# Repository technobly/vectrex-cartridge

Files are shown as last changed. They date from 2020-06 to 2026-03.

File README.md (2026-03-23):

Vectrex Cartridge and Vectrex LED board
===

So you wanna produce a Vectrex game and you need a 32KB cartridge with high score save support? Here's your reference design! Order it as is or customize it with your own graphics.  Supports 32KB and 64KB bankswitched games.  Supports 32KB games with DS2431+ high score save.  See Schematic for configuration options.

The RGB LED is also optional, but looks great in the translucent cartridge shells.  It lights up one of 8 colors based on the Red-Green-Blue DIP switch, yes black is a color of light ;-)

What makes this Vectrex Cartridge design different from others out there?  Well, the design is originally based on Frank Buss' Vectrex cart edge connector, but it has been significantly fixed.  The soldermask has been removed from around all of the fingers, the fingers themselves are not as wide as Frank's, and the spacing of everything has been updated to match original carts as close as possible.

Yes these fit in [Sean Kelly reproduction cartridge shells](http://www.vectrexmulti.com/order2.html#!/Vectrex-Empty-Cartridge-Shells/c/38886086/offset=0&sort=normal) perfectly!

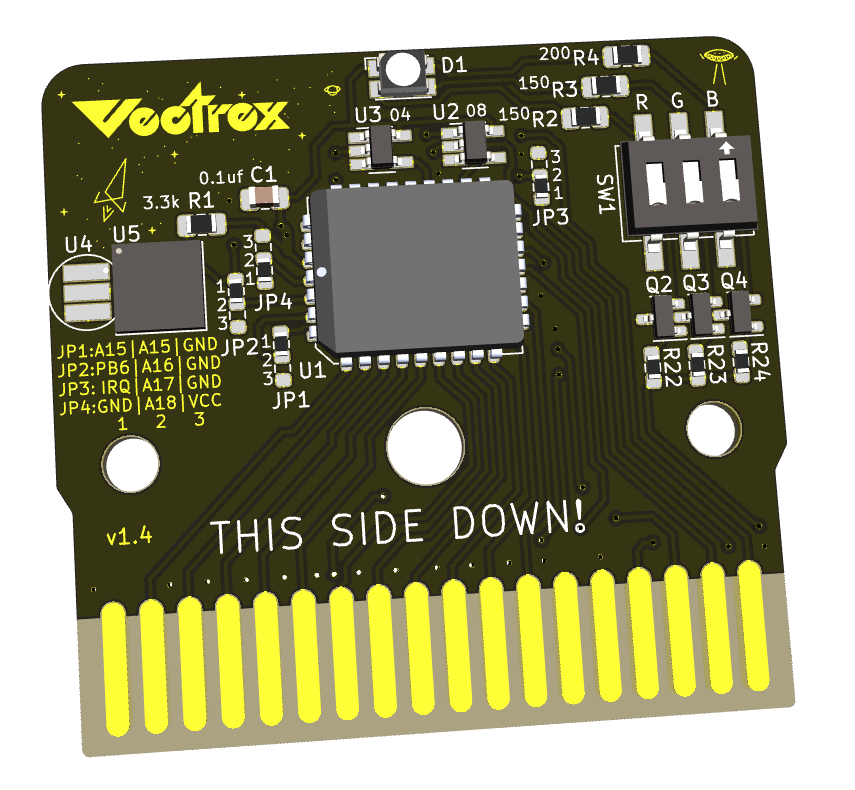
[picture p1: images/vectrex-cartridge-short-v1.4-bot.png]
v1.4 Cartridge Short Render


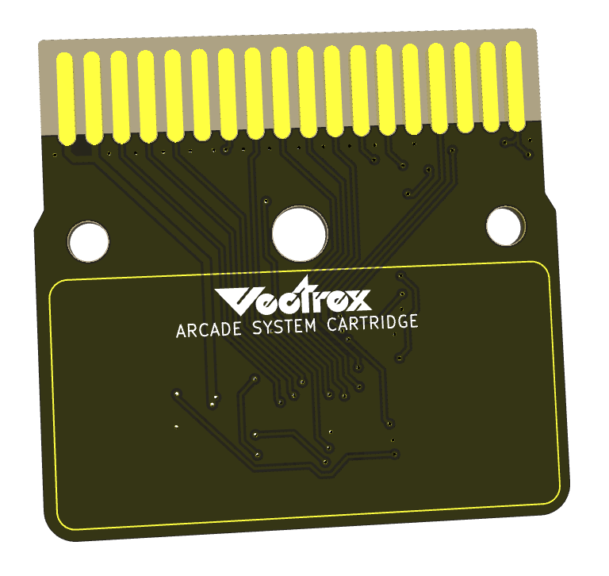
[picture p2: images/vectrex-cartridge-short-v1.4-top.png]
v1.4 Cartridge Short Render


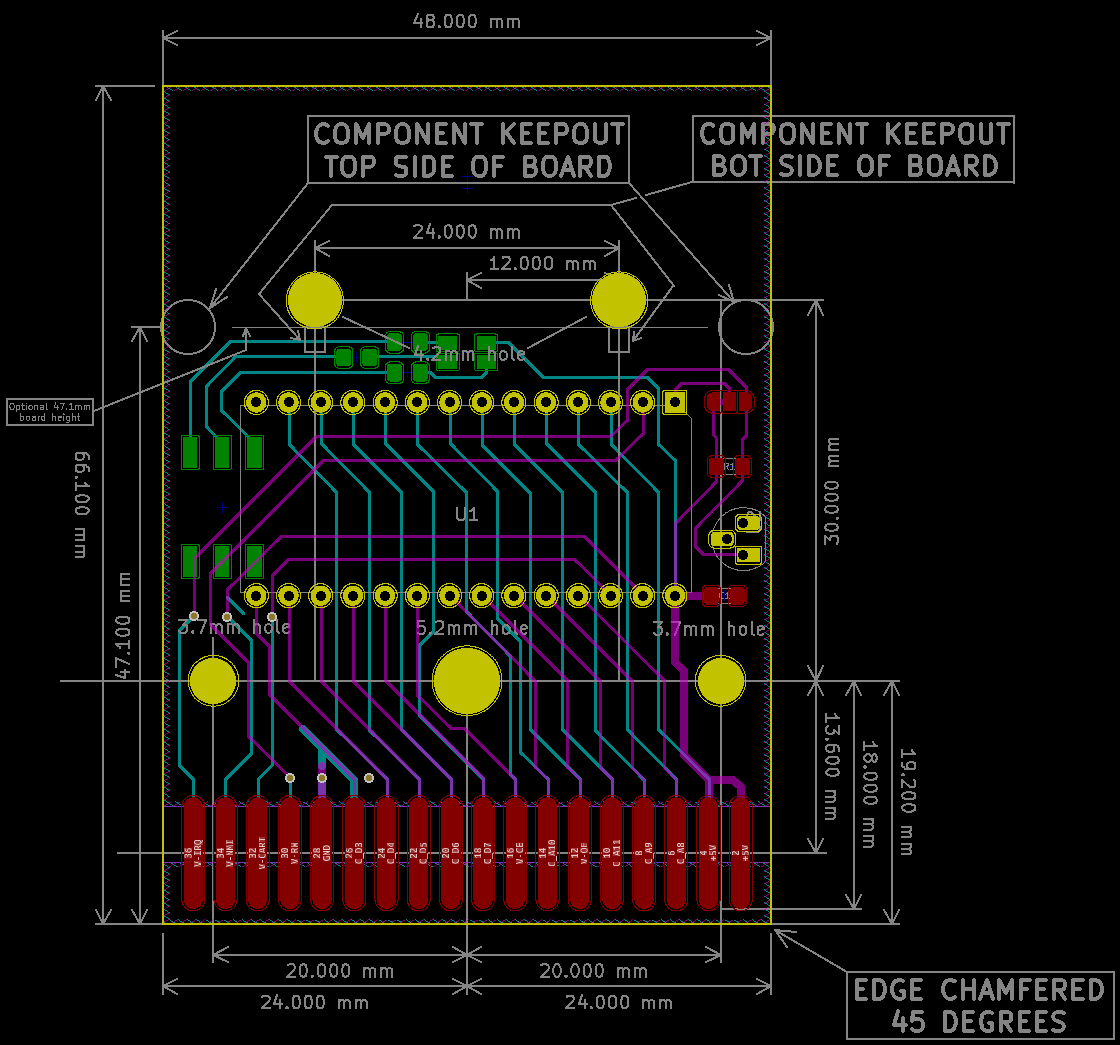
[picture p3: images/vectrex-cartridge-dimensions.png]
Dimensions


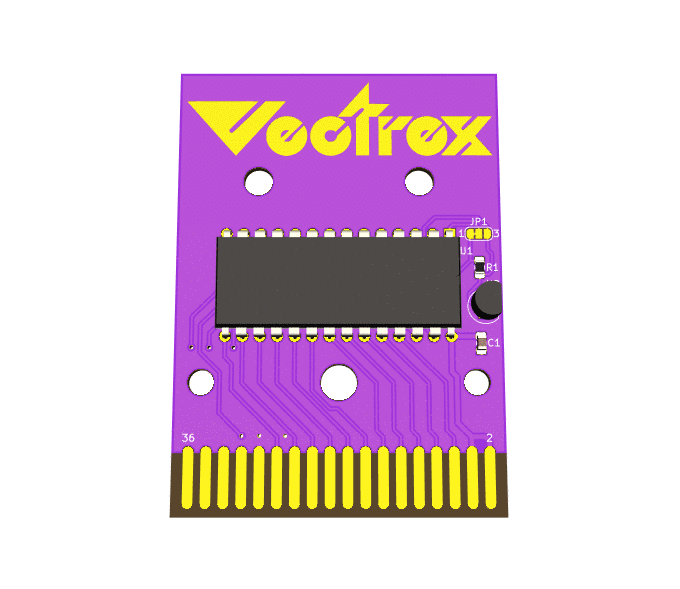
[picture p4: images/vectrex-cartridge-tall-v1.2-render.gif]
v1.2 Cartridge Render


Also included here is a simple RGB LED board add-on.  Maybe you already have a PCB but you don't have the cool LED? Easy, just add this one to the bottom.  It fits perfectly under most 28 pin 32KB/64KB EPROMS.

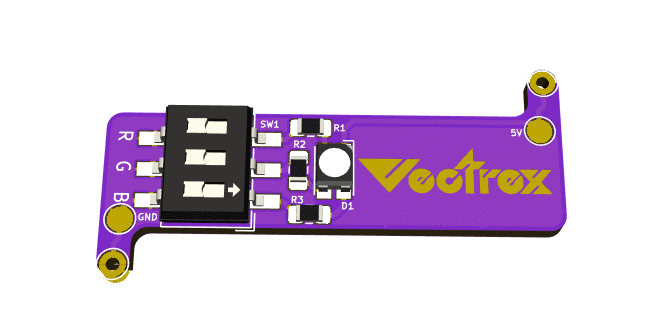
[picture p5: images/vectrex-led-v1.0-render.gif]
v1.0 LED Render


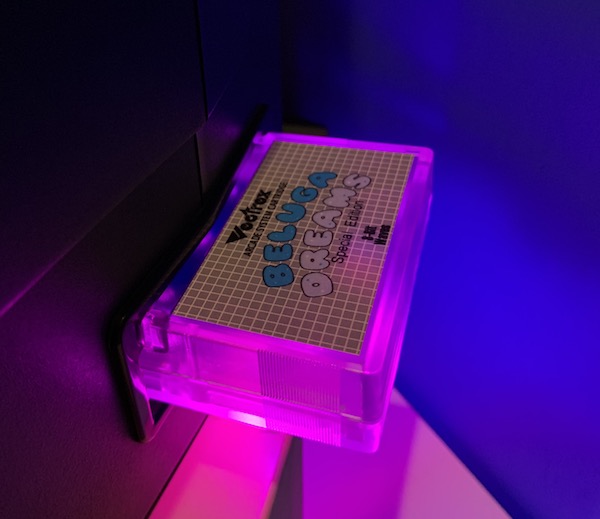
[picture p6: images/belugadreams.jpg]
Example Glow


Got a Custom PCB logo request?
===
Join the [VEXTREME Discord server](https://discord.gg/VDssGVJ) to chat with @technobly about your request

BOM and Parts ordering
===

All the parts are described in [Bill of Materials](bom/)

You can use these Digi-Key shared carts to order the parts!
[Vectrex Cartridge](https://www.digikey.com/short/z2vf9n) or
[Vectrex LED](https://www.digikey.com/short/z2vf4d)

Ordering PCB's
===

OSHPark is a good place to order with purple or the new "after dark" theme color scheme.  You can upload the KiCad `vextrex-cartridge-tall.kicad_pcb` or `vextrex-cartridge-short.kicad_pcb` there directly.  I would download this entire Github repo ZIP file first though instead of just trying to save the PCB file from your browser.  Here's a shared link for [Vectrex LED v1.0](https://oshpark.com/shared_projects/dIH6AJOJ)

Another way to order PCB's is by using the included [gerbers-tall-design](gerbers/vectrex-cartridge-tall-v1.2.zip) or [gerbers-short-design](gerbers/vectrex-cartridge-short-v1.4.zip) and uploading those with all of the necessary specs to companies like [PCBWay](https://www.pcbway.com) or [JLCPCB](https://jlcpcb.com)

## :pencil: **Don't forget to make your board finish at least ENIG (gold flash) with a 45 degree chamfered edge. [Check out my test video here on why you don't want to settle for HASL finish.](https://www.youtube.com/watch?v=6tANHqar0rI&ab_channel=PlayVectrex)**

## :boom: **[How to Build a Vectrex Game Cartridge](https://www.youtube.com/watch?v=CAzmB-9mdWY)**

Or with hard gold contacts if you really want to spend some money, and make a cart that will last forever.

LICENSE
===

CERN OHL v2.0 Permissive - essentially do whatever you want, but if you make a ton of money off of this... [buy me some coffees please!](https://buymeacoffee.com/XzUGYrhL3)  Full [LICENSE here](LICENSE)

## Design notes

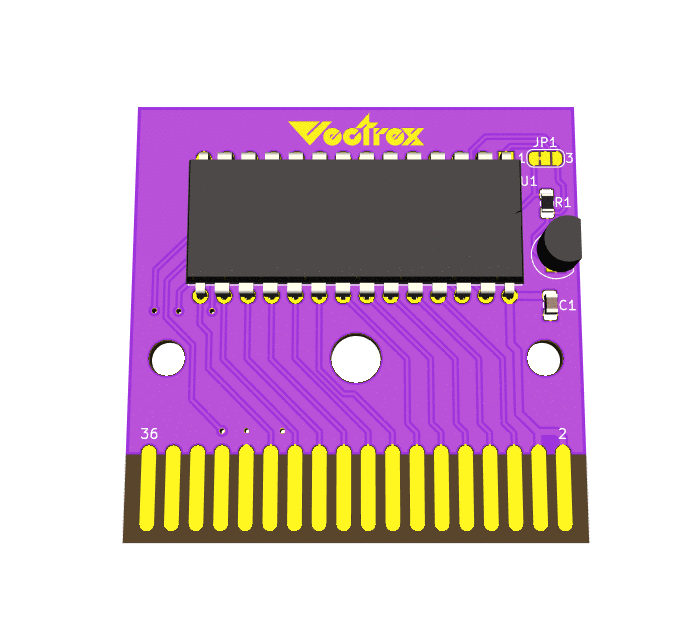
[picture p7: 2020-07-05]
images/vectrex-cartridge-short-v1.2-render.gif

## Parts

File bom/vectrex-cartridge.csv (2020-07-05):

Date: | Sunday, July 05, 2020 at 06:24:21 PM
Tool: | Eeschema (5.1.6-0)
Generator: | /Applications/KiCad/kicad.app/Contents/SharedSupport/plugins/bom_csv_grouped_by_value_with_fp.py
Component Count: | 16
Ref | Qnty | Value | Cmp name | Footprint | Description | Vendor
C1, | 1 | 0.1uF 0805 | C | Capacitor_SMD:C_0805_2012Metric_Pad1.15x1.40mm_HandSolder | Unpolarized capacitor
CON1, | 1 | vectrex-edge-connector | vectrex-edge-connector | vectrex-cartridge:vectrex-edge-connector-thinner-no-soldermask
D1, | 1 | ASMB-MTB0-0A3A2 | ASMB-MTB0-0A3A2 | vectrex-cartridge:LED_Avago_PLCC4_3.2x2.8mm_CW | Tricolor Black Surface LED, Common Anode Pin 1, PLCC-4
R1, | 1 | 3.3k 0805 | R | Resistor_SMD:R_0805_2012Metric_Pad1.15x1.40mm_HandSolder | Resistor
R2, R3, | 2 | 200 0805 | R | Resistor_SMD:R_0805_2012Metric_Pad1.15x1.40mm_HandSolder | Resistor
R4, | 1 | 120 0805 | R | Resistor_SMD:R_0805_2012Metric_Pad1.15x1.40mm_HandSolder | Resistor
SW1, | 1 | SW_DIP_x03 | SW_DIP_x03 | Button_Switch_SMD:SW_DIP_SPSTx03_Slide_6.7x9.18mm_W8.61mm_P2.54mm_LowProfile | 3x DIP Switch, Single Pole Single Throw (SPST) switch, small symbol
U1, | 1 | AT27C256R-70PU / AT27C512R-70PU | 27C512 | Package_DIP:DIP-28_W15.24mm | OTP EPROM 512 KiBit
U2, | 1 | DS2431+ TO-92 | DS2431 | vectrex-cartridge:TO-92_Inline_BW

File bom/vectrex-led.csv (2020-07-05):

Date: | Sunday, July 05, 2020 at 06:26:26 PM
Tool: | Eeschema (5.1.6-0)
Generator: | /Applications/KiCad/kicad.app/Contents/SharedSupport/plugins/bom_csv_grouped_by_value_with_fp.py
Component Count: | 10
Ref | Qnty | Value | Cmp name | Footprint | Description | Vendor
D1, | 1 | ASMB-MTB0-0A3A2 | ASMB-MTB0-0A3A2 | vectrex-cartridge:LED_Avago_PLCC4_3.2x2.8mm_CW | Tricolor Black Surface LED, Common Anode Pin 1, PLCC-4
R1, R2, | 2 | 200 0805 | R | Resistor_SMD:R_0805_2012Metric_Pad1.15x1.40mm_HandSolder | Resistor
R3, | 1 | 120 0805 | R | Resistor_SMD:R_0805_2012Metric_Pad1.15x1.40mm_HandSolder | Resistor
SW1, | 1 | SW_DIP_x03 | SW_DIP_x03 | Button_Switch_SMD:SW_DIP_SPSTx03_Slide_6.7x9.18mm_W8.61mm_P2.54mm_LowProfile | 3x DIP Switch, Single Pole Single Throw (SPST) switch, small symbol

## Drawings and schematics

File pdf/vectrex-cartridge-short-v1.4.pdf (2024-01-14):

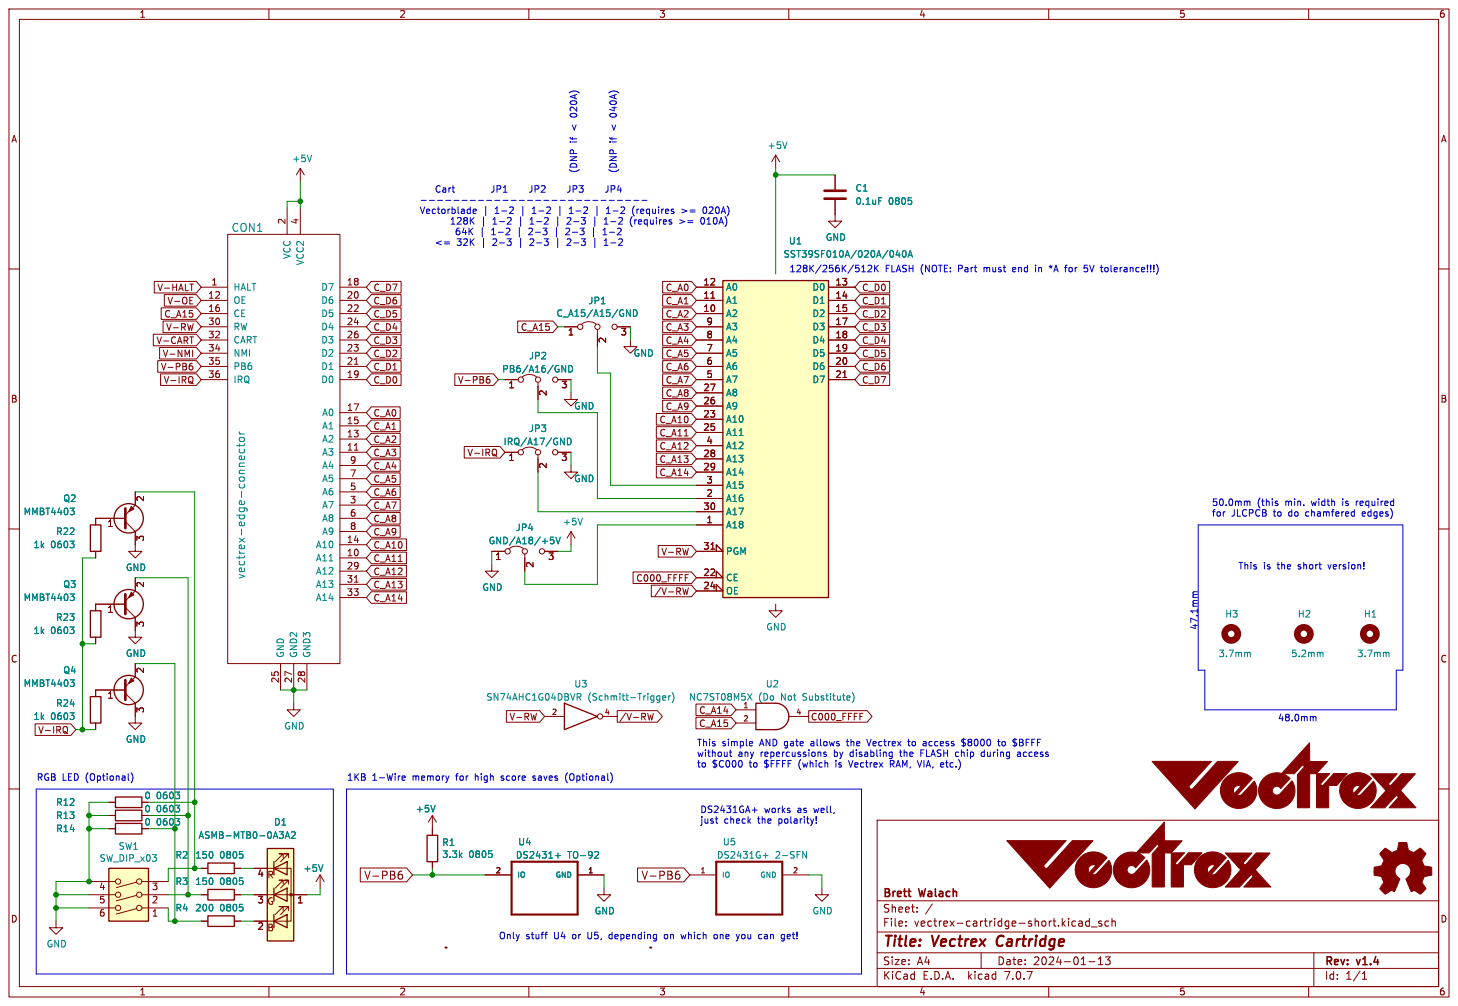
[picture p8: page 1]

2 D6 20 D1 21 D5 22 D2 23 D4 24 GND 25 D3 26 GND2 27 GND3 28 A12 29 A7 3 RW 30 A13 31 CART 32 A14 33 NMI 34 PB6 35

to $C000 to $FFFF (which is Vectrex RAM, VIA, etc.) Q3 MMBT4403

File: vectrex-cartridge-short.kicad_sch Sheet: / Brett Walach R1

Id: 1/1 Title: Vectrex Cartridge

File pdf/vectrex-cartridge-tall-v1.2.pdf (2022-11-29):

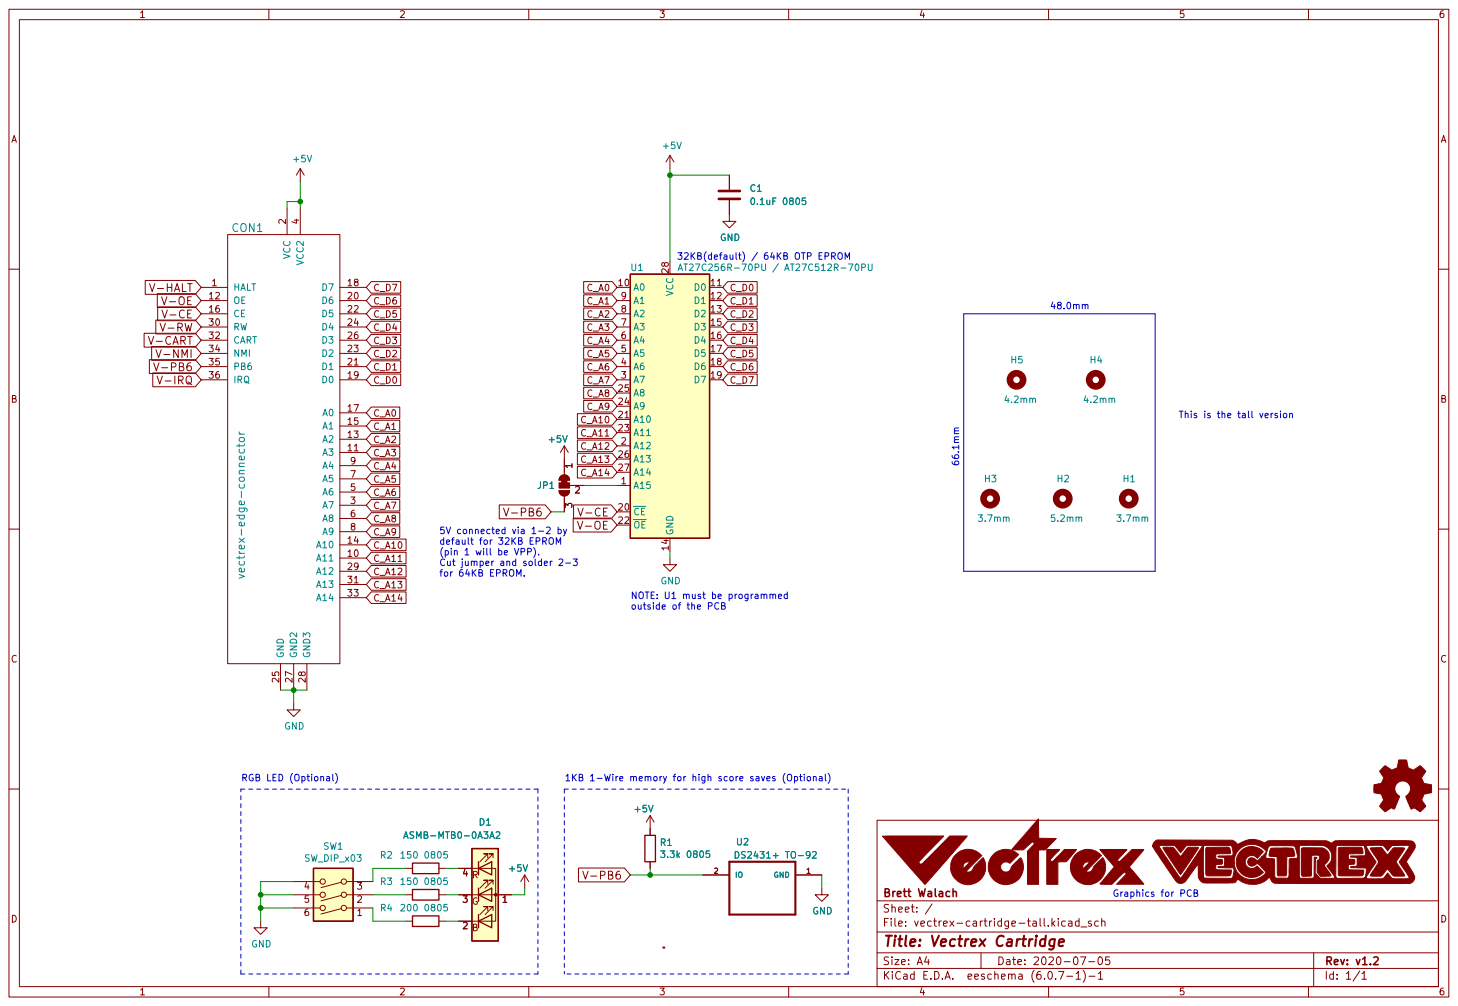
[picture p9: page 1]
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

5V connected via 1-2 by default for 32KB EPROM (pin 1 will be VPP).

Cut jumper and solder 2-3

Id: 1/1 Title: Vectrex Cartridge

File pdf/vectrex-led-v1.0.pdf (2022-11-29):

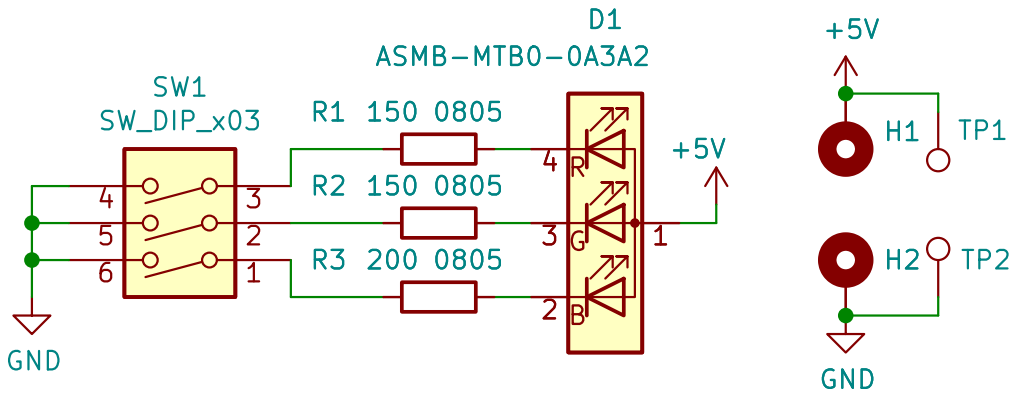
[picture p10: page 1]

File: vectrex-led.kicad_sch Sheet: / Brett Walach GND

Id: 1/1 Title: Vectrex RGB LED

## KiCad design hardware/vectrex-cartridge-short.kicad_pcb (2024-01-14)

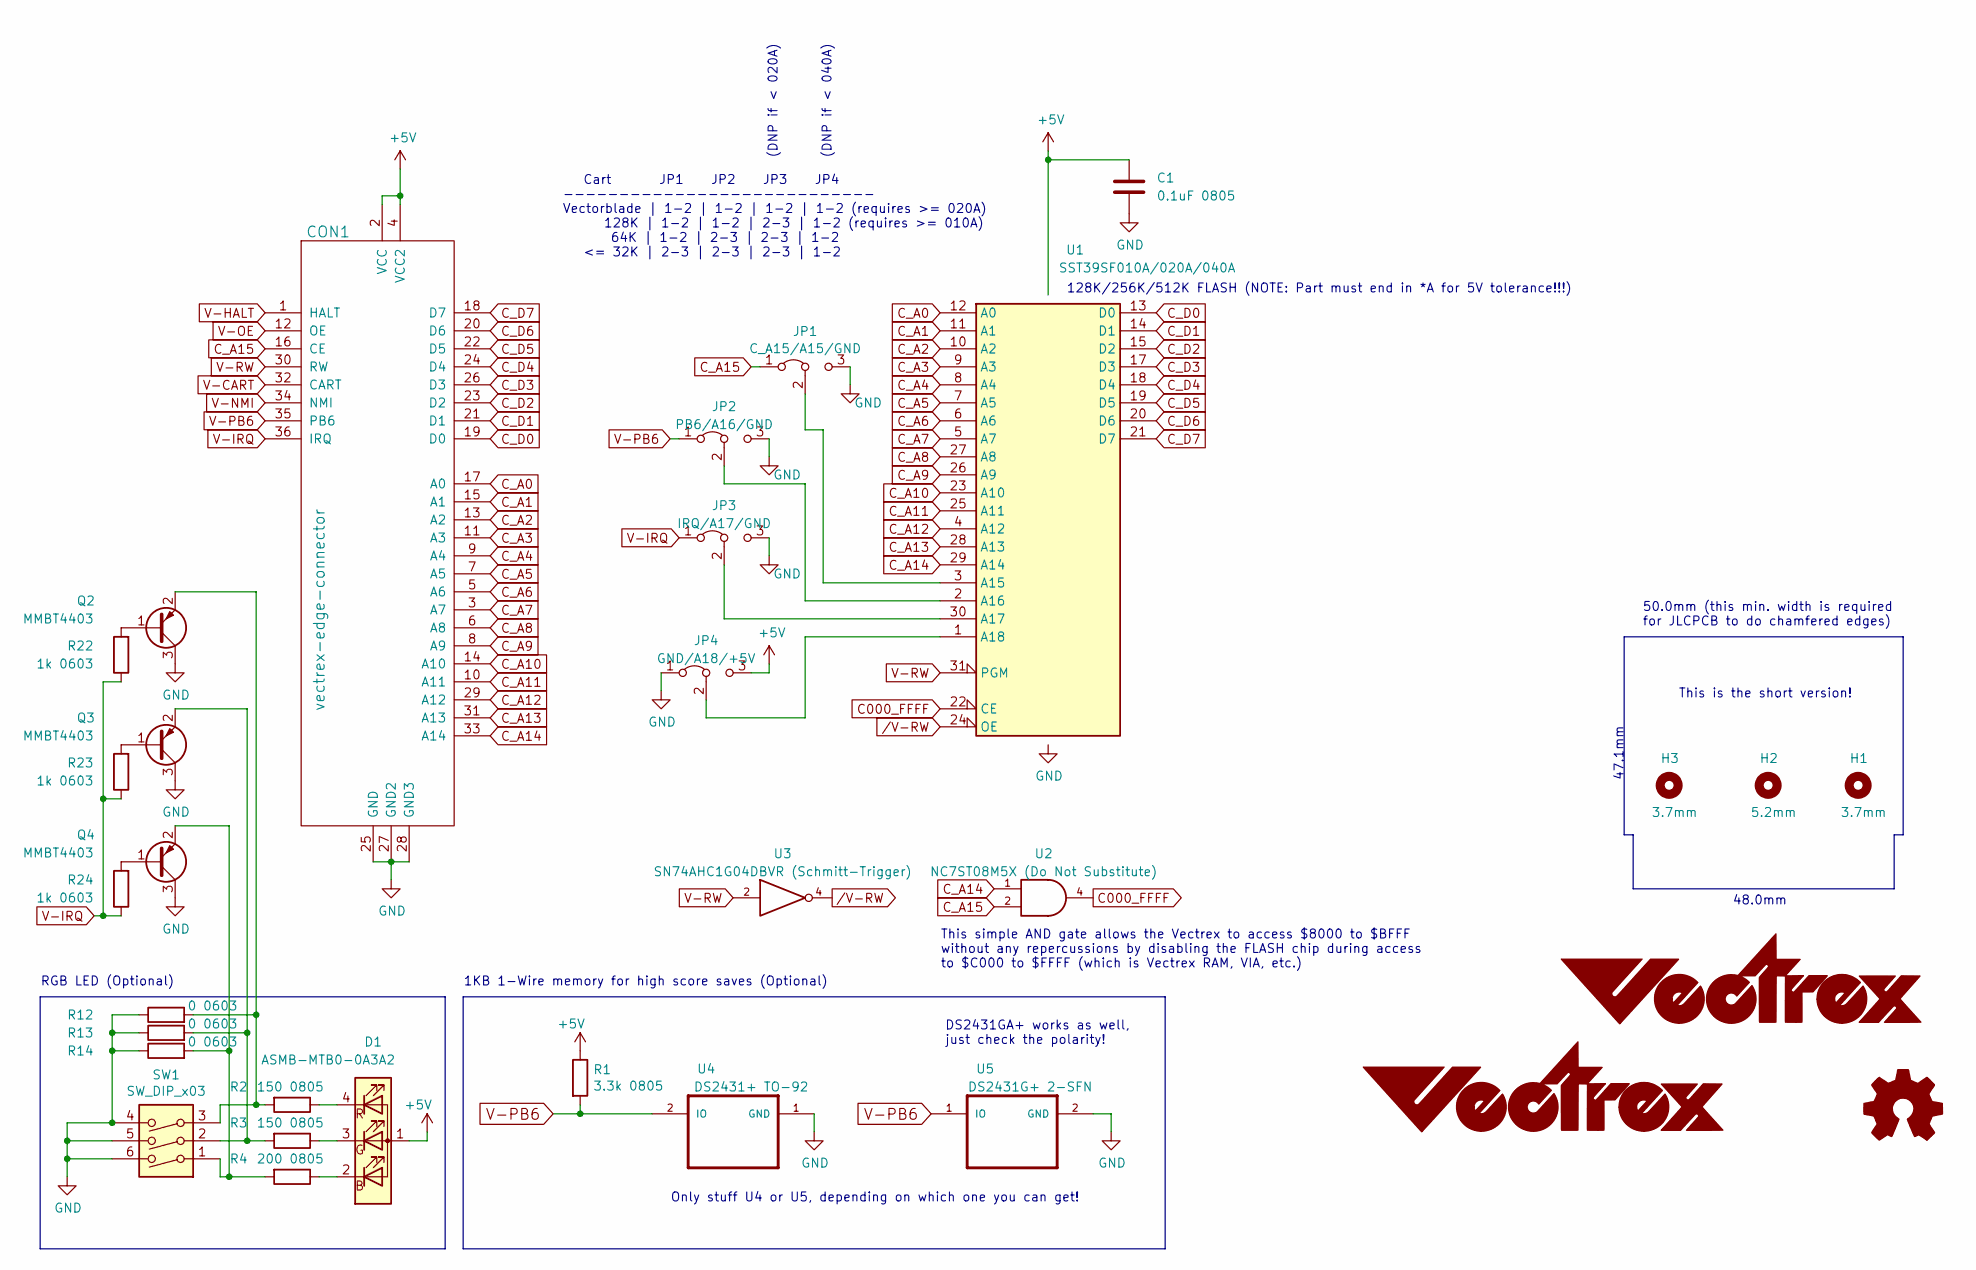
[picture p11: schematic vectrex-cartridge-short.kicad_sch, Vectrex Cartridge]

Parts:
C1: 0.1uF 0805; C_0805_2012Metric_Pad1.15x1.40mm_HandSolder
CON1: vectrex-edge-connector; vectrex-edge-connector-thinner-no-soldermask-no-silk
D1: ASMB-MTB0-0A3A2; LED_Avago_PLCC4_3.2x2.8mm_CW
G1: LOGO; vectrex-us-soldermask-15mm
G2: LOGO; vectrex-us-silkscreen-15mm
H1, H3: 3.7mm; Mounting_Hole_D3.7mm
H2: 5.2mm; Mounting_Hole_D5.2mm
JP1: C_A15/A15/GND; R_0603_1608Metric_Jumper_12_Bridged
JP2: PB6/A16/GND; R_0603_1608Metric_Jumper_12_Bridged
JP3: IRQ/A17/GND; R_0603_1608Metric_Jumper_12_Bridged
JP4: GND/A18/+5V; R_0603_1608Metric_Jumper_12_Bridged
Q2, Q3, Q4: MMBT4403; SOT-23
R1: 3.3k 0805; R_0805_2012Metric_Pad1.15x1.40mm_HandSolder
R2, R3: 150 0805; R_0805_2012Metric_Pad1.15x1.40mm_HandSolder
R4: 200 0805; R_0805_2012Metric_Pad1.15x1.40mm_HandSolder
R12, R13, R14: 0 0603; R_0603_1608Metric_Pad0.98x0.95mm_HandSolder
R22, R23, R24: 1k 0603; R_0603_1608Metric_Pad0.98x0.95mm_HandSolder
SW1: SW_DIP_x03; SW_DIP_SPSTx03_Slide_6.7x9.18mm_W8.61mm_P2.54mm_LowProfile_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
U1: SST39SF010A/020A/040A; PLCC-32_11.4x14.0mm_P1.27mm
U2: NC7ST08M5X (Do Not Substitute); SOT-23-5_HandSoldering
U3: SN74AHC1G04DBVR (Schmitt-Trigger); SOT-23-5_HandSoldering
U4: DS2431+ TO-92; TO-92_Inline_BW_SMT
U5: DS2431G+ 2-SFN; 2SFN_6mmx6mm

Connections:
+5V: C1.1, CON1.2 (VCC), CON1.4 (VCC2), D1.1 (A), JP4.3 (B), R1.1, U1.32 (VCC), U2.5 (VCC), U3.5 (VCC)
C000_FFFF: U1.22 (CE), U2.4
C_A0: CON1.17 (A0), U1.12 (A0)
C_A1: CON1.15 (A1), U1.11 (A1)
C_A2: CON1.13 (A2), U1.10 (A2)
C_A3: CON1.11 (A3), U1.9 (A3)
C_A4: CON1.9 (A4), U1.8 (A4)
C_A5: CON1.7 (A5), U1.7 (A5)
C_A6: CON1.5 (A6), U1.6 (A6)
C_A7: CON1.3 (A7), U1.5 (A7)
C_A8: CON1.6 (A8), U1.27 (A8)
C_A9: CON1.8 (A9), U1.26 (A9)
C_A10: CON1.14 (A10), U1.23 (A10)
C_A11: CON1.10 (A11), U1.25 (A11)
C_A12: CON1.29 (A12), U1.4 (A12)
C_A13: CON1.31 (A13), U1.28 (A13)
C_A14: CON1.33 (A14), U1.29 (A14), U2.1
C_A15: CON1.16 (CE), JP1.1 (A), U2.2
C_D0: CON1.19 (D0), U1.13 (D0)
C_D1: CON1.21 (D1), U1.14 (D1)
C_D2: CON1.23 (D2), U1.15 (D2)
C_D3: CON1.26 (D3), U1.17 (D3)
C_D4: CON1.24 (D4), U1.18 (D4)
C_D5: CON1.22 (D5), U1.19 (D5)
C_D6: CON1.20 (D6), U1.20 (D6)
C_D7: CON1.18 (D7), U1.21 (D7)
GND: C1.2, CON1.25 (GND), CON1.27 (GND2), CON1.28 (GND3), JP1.3 (B), JP2.3 (B), JP3.3 (B), JP4.1 (A), Q2.3 (C), Q3.3 (C), Q4.3 (C), R12.1, R13.1, R14.1, SW1.4, SW1.5, SW1.6, U1.16 (GND), U2.3 (GND), U3.3 (GND), U4.1 (GND), U5.2 (GND)
unnamed: D1.2 (BK), R4.1
unnamed: D1.3 (GK), R3.1
unnamed: D1.4 (RK), R2.1
unnamed: JP1.2 (C), U1.3 (A15)
unnamed: JP2.2 (C), U1.2 (A16)
unnamed: JP3.2 (C), U1.30 (A17)
unnamed: JP4.2 (C), U1.1 (A18)
unnamed: Q2.1 (B), R22.2
unnamed: Q2.2 (E), R2.2, R12.2, SW1.3
unnamed: Q3.1 (B), R23.2
unnamed: Q3.2 (E), R3.2, R13.2, SW1.2
unnamed: Q4.1 (B), R24.2
unnamed: Q4.2 (E), R4.2, R14.2, SW1.1
V-CART: CON1.32 (CART)
V-HALT: CON1.1 (HALT)
V-IRQ: CON1.36 (IRQ), JP3.1 (A), R22.1, R23.1, R24.1
V-NMI: CON1.34 (NMI)
V-OE: CON1.12 (OE)
V-PB6: CON1.35 (PB6), JP2.1 (A), R1.2, U4.2 (IO), U5.1 (IO)
V-RW: CON1.30 (RW), U1.31 (PGM), U3.2
/V-RW: U1.24 (OE), U3.4

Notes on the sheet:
Only stuff U4 or U5, depending on which one you can get!
50.0mm (this min. width is required for JLCPCB to do chamfered edges)
(DNP if < 020A)
1KB 1-Wire memory for high score saves (Optional)
RGB LED (Optional)
48.0mm
This is the short version!
Cart JP1 JP2 JP3 JP4 ---------------------------- Vectorblade | 1-2 | 1-2 | 1-2 | 1-2 (requires >= 020A) 128K | 1-2 | 1-2 | 2-3 | 1-2 (requires >= 010A) 64K | 1-2 | 2-3 | 2-3 | 1-2 <= 32K | 2-3 | 2-3 | 2-3 | 1-2
128K/256K/512K FLASH (NOTE: Part must end in *A for 5V tolerance!!!)
DS2431GA+ works as well, just check the polarity!
(DNP if < 040A)
47.1mm
This simple AND gate allows the Vectrex to access $8000 to $BFFF without any repercussions by disabling the FLASH chip during access to $C000 to $FFFF (which is Vectrex RAM, VIA, etc.)

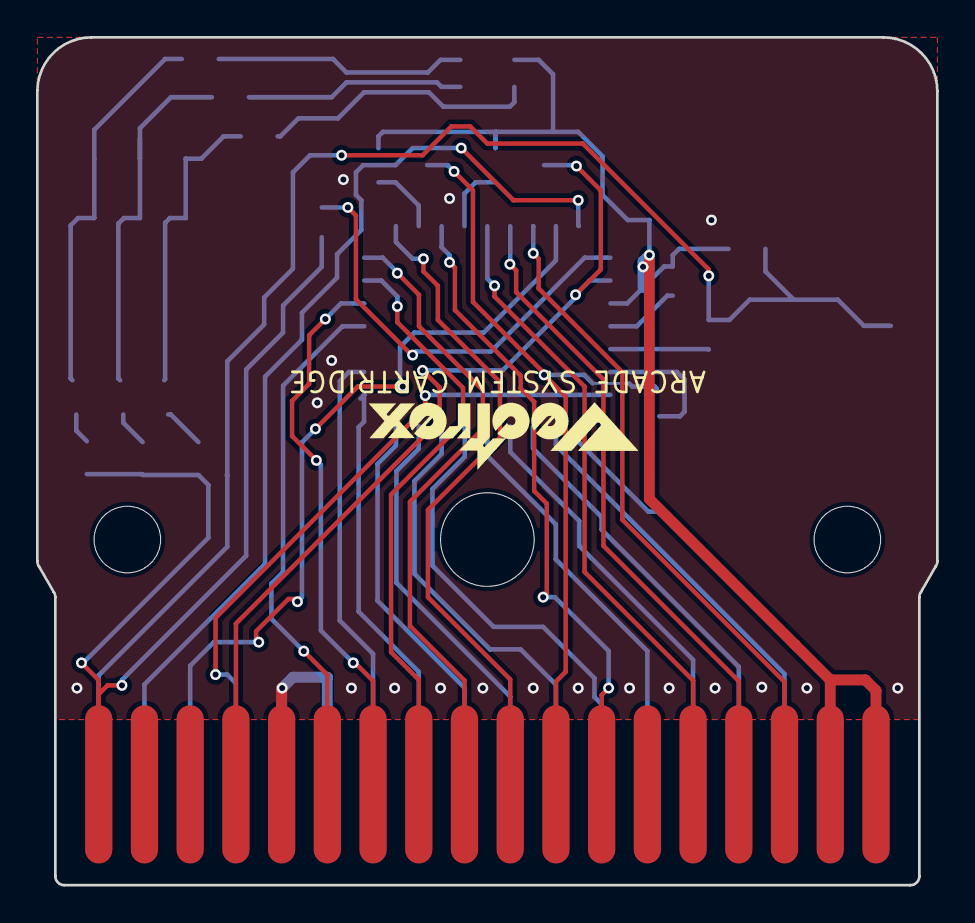
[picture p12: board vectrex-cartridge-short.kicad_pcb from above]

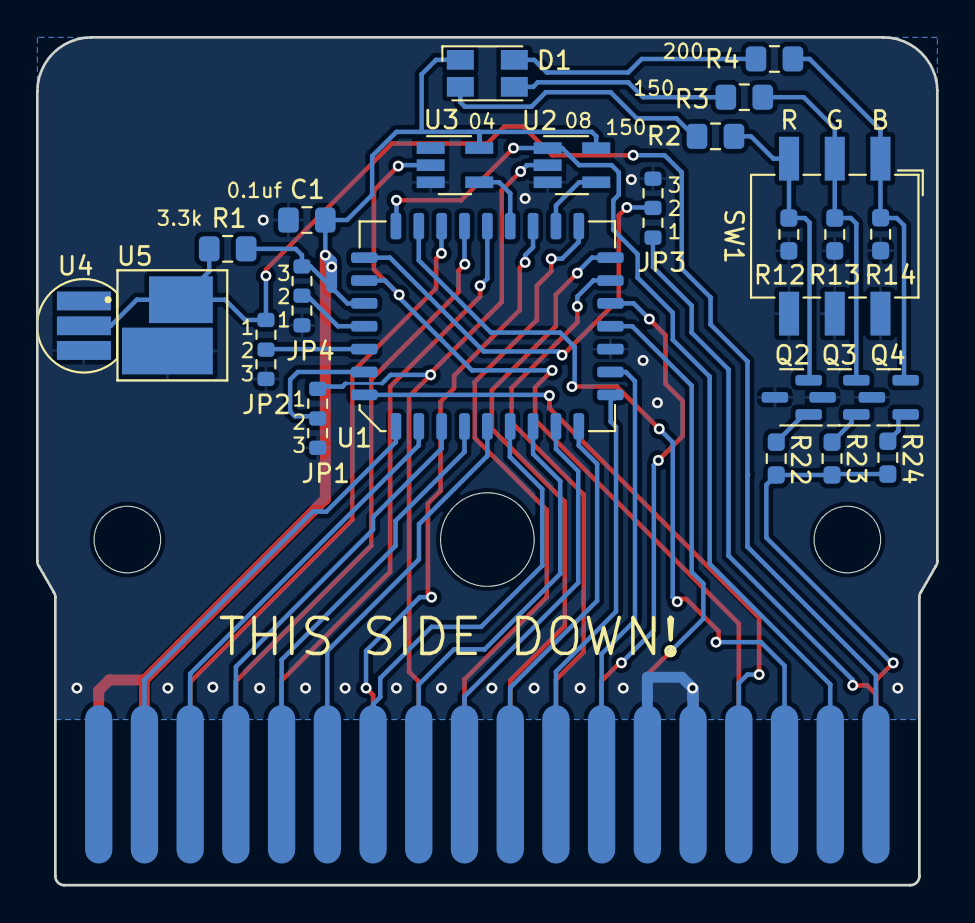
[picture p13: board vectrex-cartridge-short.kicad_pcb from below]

Board: 2 copper layers, 50.0 x 47.1 mm, 31 parts (26 on the bottom side), 44 nets.

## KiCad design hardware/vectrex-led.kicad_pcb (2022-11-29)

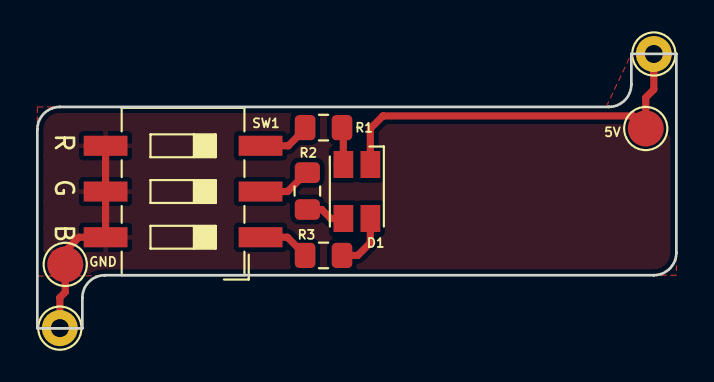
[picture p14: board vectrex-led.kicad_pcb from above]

Board: 2 copper layers, 35.5 x 15.2 mm, 10 parts (0 on the bottom side), 8 nets.

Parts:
D1: ASMB-MTB0-0A3A2; LED_Avago_PLCC4_3.2x2.8mm_CW
G1: LOGO; vectrex-us-soldermask-15mm
H1, H2: MountingHole_Pad; TestPoint_THTPad_D2.0mm_Drill1.0mm
R1, R2: 220 0805; R_0805_2012Metric_Pad1.15x1.40mm_HandSolder
R3: 150 0805; R_0805_2012Metric_Pad1.15x1.40mm_HandSolder
SW1: SW_DIP_x03; SW_DIP_SPSTx03_Slide_6.7x9.18mm_W8.61mm_P2.54mm_LowProfile
TP1, TP2: TestPoint; TestPoint_Pad_D2.0mm

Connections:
+5V: D1.1, H1.1, TP1.1
GND: H2.1, SW1.4, SW1.5, SW1.6, TP2.1
unnamed: D1.2, R3.1
unnamed: D1.3, R2.1
unnamed: D1.4, R1.1
unnamed: R1.2, SW1.3
unnamed: R2.2, SW1.2
unnamed: R3.2, SW1.1

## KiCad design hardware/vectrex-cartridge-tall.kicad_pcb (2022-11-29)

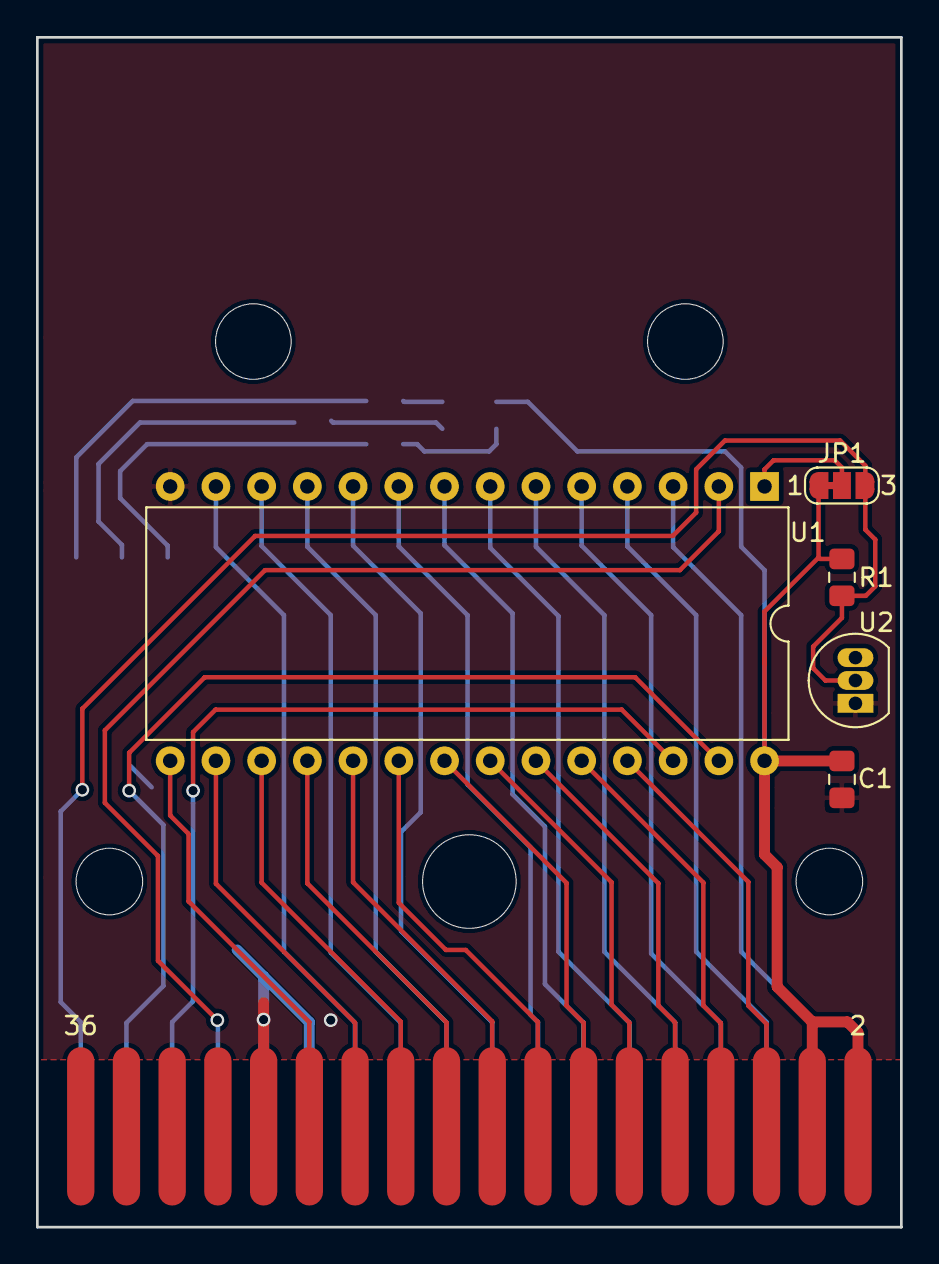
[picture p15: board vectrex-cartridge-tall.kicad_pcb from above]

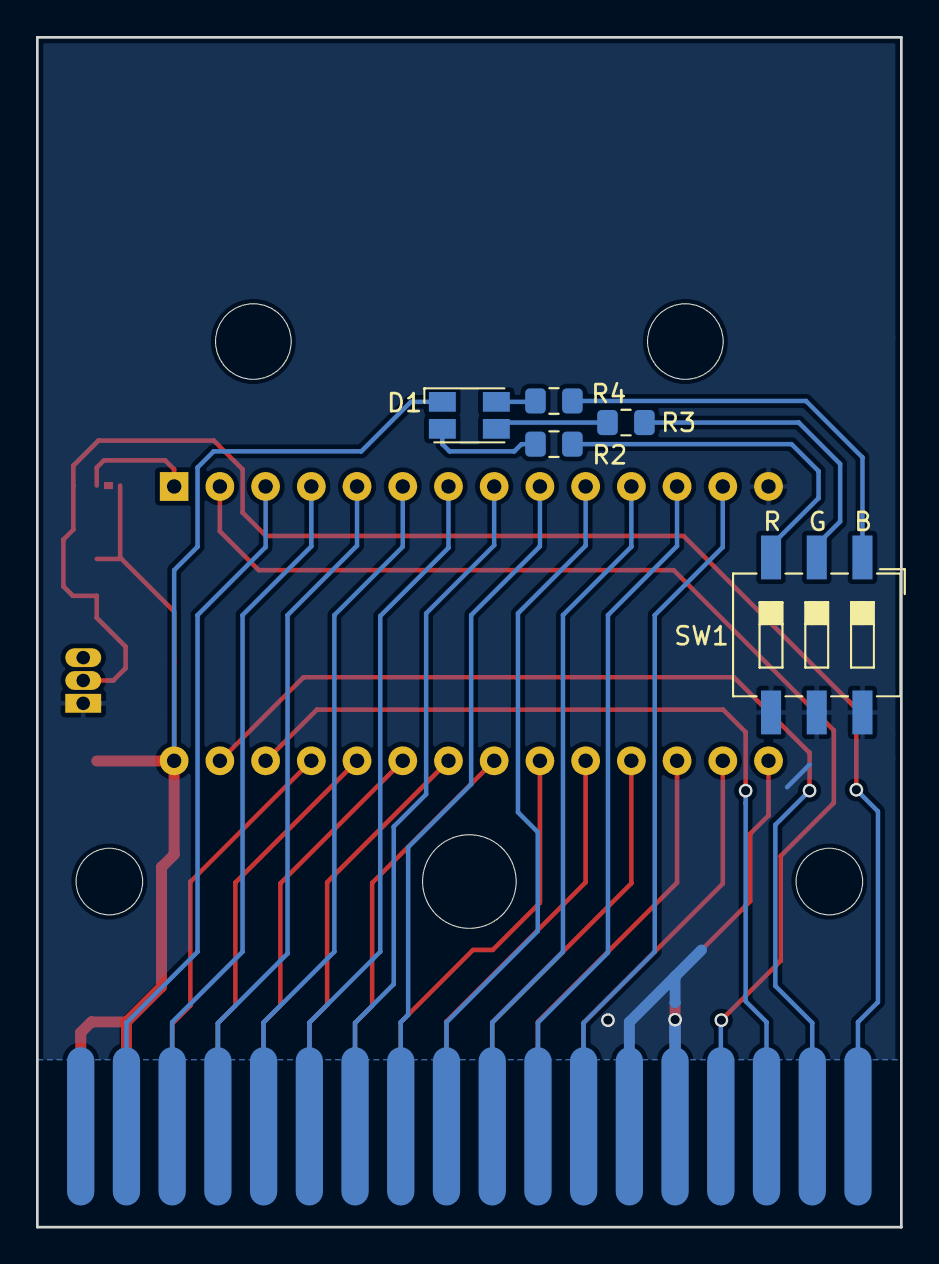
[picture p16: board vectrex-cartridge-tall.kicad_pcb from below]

Board: 2 copper layers, 48.0 x 66.1 mm, 18 parts (6 on the bottom side), 35 nets.

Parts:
C1: 0.1uF 0805; C_0805_2012Metric_Pad1.15x1.40mm_HandSolder
CON1: vectrex-edge-connector; vectrex-edge-connector-thinner-no-soldermask
D1: ASMB-MTB0-0A3A2; LED_Avago_PLCC4_3.2x2.8mm_CW
G1: LOGO; vectrex-us-soldermask
G3: LOGO; vectrex-uk-soldermask
H1, H3: 3.7mm; Mounting_Hole_D3.7mm
H2: 5.2mm; Mounting_Hole_D5.2mm
H4, H5: 4.2mm; Mounting_Hole_D4.2mm
JP1: SolderJumper_3_Bridged12; SolderJumper-3_P1.3mm_Bridged12_RoundedPad1.0x1.5mm_NumberL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
R1: 3.3k 0805; R_0805_2012Metric_Pad1.15x1.40mm_HandSolder
R2, R3: 200 0805; R_0805_2012Metric_Pad1.15x1.40mm_HandSolder
R4: 120 0805; R_0805_2012Metric_Pad1.15x1.40mm_HandSolder
SW1: SW_DIP_x03; SW_DIP_SPSTx03_Slide_6.7x9.18mm_W8.61mm_P2.54mm_LowProfile
U1: AT27C256R-70PU / AT27C512R-70PU; DIP-28_W15.24mm
U2: DS2431+ TO-92; TO-92_Inline_BW

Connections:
+5V: C1.1, CON1.2, CON1.4, D1.1, JP1.1, R1.1, U1.28
C_A0: CON1.17, U1.10
C_A1: CON1.15, U1.9
C_A2: CON1.13, U1.8
C_A3: CON1.11, U1.7
C_A4: CON1.9, U1.6
C_A5: CON1.7, U1.5
C_A6: CON1.5, U1.4
C_A7: CON1.3, U1.3
C_A8: CON1.6, U1.25
C_A9: CON1.8, U1.24
C_A10: CON1.14, U1.21
C_A11: CON1.10, U1.23
C_A12: CON1.29, U1.2
C_A13: CON1.31, U1.26
C_A14: CON1.33, U1.27
C_D0: CON1.19, U1.11
C_D1: CON1.21, U1.12
C_D2: CON1.23, U1.13
C_D3: CON1.26, U1.15
C_D4: CON1.24, U1.16
C_D5: CON1.22, U1.17
C_D6: CON1.20, U1.18
C_D7: CON1.18, U1.19
GND: C1.2, CON1.25, CON1.27, CON1.28, SW1.4, SW1.5, SW1.6, U1.14, U2.1
unnamed: D1.2, R4.1
unnamed: D1.3, R3.1
unnamed: D1.4, R2.1
unnamed: JP1.2, U1.1
unnamed: R2.2, SW1.3
unnamed: R3.2, SW1.2
unnamed: R4.2, SW1.1
V-CE: CON1.16, U1.20
V-OE: CON1.12, U1.22
V-PB6: CON1.35, JP1.3, R1.2, U2.2

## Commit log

2020-06-21 initial release v1.0
    [vectrex-cartridge-B_Cu.gbl, vectrex-cartridge-B_Mask.gbs, vectrex-cartridge-B_Paste.gbp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]
2020-06-22 added short design gerber zip file
2020-06-29 added RGB LED to Vectrex Cartridge v1.1, also added stand-alone LED PCB v1.0
    [vectrex-cartridge-B_Cu.gbl, vectrex-cartridge-B_Mask.gbs, vectrex-cartridge-B_Paste.gbp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]
2020-07-05 Updated DS2431 footprint, and many little tweaks for v1.2
    [vectrex-cartridge-short.kicad_pcb, vectrex-cartridge-short.sch, vectrex-cartridge-tall.kicad_pcb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]
2020-09-25 Updated LED resistor values for deeper colors.
2022-11-29 migrate symbol libraries to KiCad 6.x
    [vectrex-cartridge-short.kicad_sch, vectrex-cartridge-tall.kicad_sch, vectrex-led.kicad_sch]
2022-11-29 migrate 3D shapes to built-in KiCad 6.x location
    [vectrex-cartridge-short.kicad_pcb, vectrex-cartridge-short.sch, vectrex-cartridge-tall.kicad_pcb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]
2022-11-29 update RGB LED resistor values for deeper color
    [vectrex-cartridge-short.kicad_sch, vectrex-cartridge-tall.kicad_sch, vectrex-led.kicad_sch]
2024-01-14 update vectrex-cartridge-short to v1.4 all SMT
    [vectrex-cartridge-short.kicad_pcb, vectrex-cartridge-short.kicad_sch]
